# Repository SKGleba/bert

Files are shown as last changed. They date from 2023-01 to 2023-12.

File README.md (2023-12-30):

# bert
*"Bert"* is a nickname given to a UART RPC interface client of PSP2's System Controller.
<br><br>
The PlayStation Vita/TV's System Controller - codenamed *"Ernie"* - is a low-power MCU that handles peripherals such as PMIC, USB controller, physical buttons, touch panels and more. 
It hosts a RPC server accessible from multiple interfaces, each of which has its own set of available commands.<br>
One of the interfaces is UART, enabled by a special *"jig"* circuit that sets specific voltage levels on syscon's voltage sense pins/probes. 
This interface exposes around 100 RPC commands ranging from simple peripheral details retrieving to more complex procedures such as flash programming or alternative SoC boot modes.<br>
In this repository you will find documentation, schematics, diagrams and scripts for interacting with Syscon over the UART interface.
<br><br>

## Hardware
Supported units:
 - DEM-3000 : **only IRT-002**
   - unknown interface-enable procedure on IRT-001 / *"slideys"*
 - CEM-3000 : **supported**
 - PDEL-1000 : **supported**
 - PCH-1000 : **supported**
 - VTE-1000 : **supported**
 - PCH-2000 : **supported**

For all supported units, the UART interface logic level is 1.8v.

### PCH-1000, DEM-3000, CEM-3000, PDEL-1000
On those units, the circuit probes as well as Syscon UART are exposed via the [MultiConnector](https://wiki.henkaku.xyz/vita/UDC#PCH-1XXX_Pinout).
 - Pin 6: Syscon RX
 - Pin 7: Syscon TX
 - Pin 11: Jig Sense 1
 - Pin 12: Jig Sense 2
 - Pin 14: GND

The UART interface is enabled if the *"Jig Sense 1"* probe is at 0.47v-0.738v during *"Jig Sense 2"* probe state change.<br>
State change can be achieved by connecting the probe to GND using a button or jumper wire.<br>
A [MultiConnector breakout board](https://github.com/SKGleba/bert/blob/main/PCBs/multicn-UDC-breakout-kicad.zip) is recommended. 
The biggest challenge is finding a populated connector, we found that the **PCH-ZCL1** *"Sony PlayStation Vita Cradle"* has one, but it is hard to source.<br>
Another possibility is using the motherboard's tiny testpads, or lifting and moving pins on a retail USB MultiConnector cable.<br>

### VTE-1000
On this unit, the circuit probes as well as Syscon and SoC UART are exposed via the [Service Connector](https://www.psdevwiki.com/vita/Service_Connectors).
 - Pin 1: GND
 - Pin 4: Jig Sense 1
 - Pin 6: Jig Sense 2
 - Pin 13: SoC TX (useful)
 - Pin 14: SoC RX (useful)
 - Pin 19: Syscon TX
 - Pin 20: Syscon RX

It is recommended to use the big testpads above the flat connector:

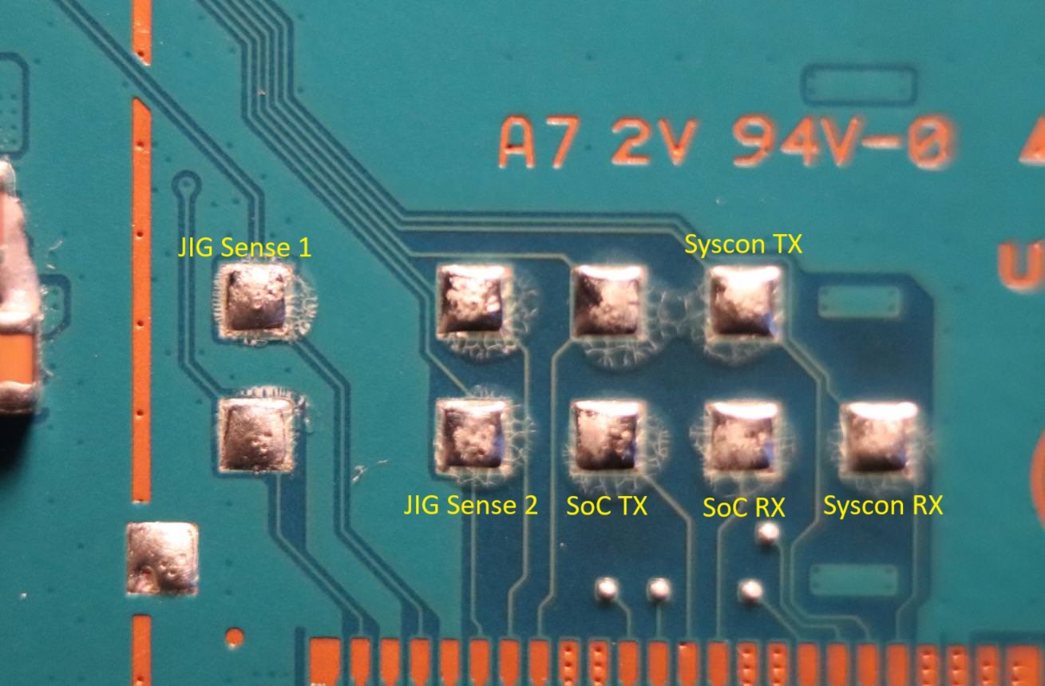
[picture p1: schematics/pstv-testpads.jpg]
pstv-testpads


The UART interface is enabled if the *"Jig Sense 1"* probe is at 0.47v-0.738v during *"Jig Sense 2"* probe state change.<br>
State change can be achieved by connecting the probe to GND using a button or jumper wire.

### PCH-2000
On this unit, the circuit probe as well as Syscon UART are exposed via [microUSB](https://wiki.henkaku.xyz/vita/UDC#PCH-2XXX_Pinout).
 - Pin 2: D- : Syscon TX
 - Pin 3: D+ : Syscon RX
 - Pin 4: ID : Jig Sense
 - Pin 5: GND

The UART interface is enabled if the *"Jig Sense"* probe is at 1.017v-1.14v for at least 32000 Syscon clock cycles. When enabled, a *"UUU"* hello packet is sent over UART.<br>
A microUSB breakout board is recommended, it is also possible to use the motherboard's big testpads.

### AIO
The following circuit will enable the Syscon UART interface on all supported units:

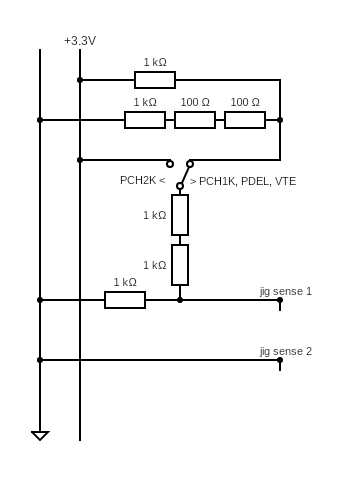
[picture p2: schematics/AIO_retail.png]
AIO-circuit

<br><br>

## Software
The UART RPC interface protocol is a simple message -> reply packet interaction, structured as below:
```C
struct _ernie_cmd {
    uint16_t id; // Command ID
    uint8_t ret; // 0x00 for message, return status for reply
    uint16_t data_size;
    uint8_t data[data_size];
    uint16_t checksum; // ~(all bytes added)
} _ernie_cmd;
```
Each packet is converted to/from ASCII and ends in CRLF, max packet size is 0x40 bytes (ascii 0x80).

### Message
A list of all available commands can be found [in commands.md](commands.md).

### Reply
The reply contains a command return status, currently the following status IDs are known:
 - 0x0 : "OK"
 - 0x1 : "UNK_CMD"
 - 0x2 : "BAD_LEN"
 - 0x3 : "BAD_CHKSUM"
 - 0x4 : "NO_CRLF"
 - 0x5 : "BAD_CMD_FORMAT"
 - 0x10 : "LOCKED_HANDSHAKE"
 - 0x20 : "LOCKED_T1"
 - 0x32 : "BAD_ARG_SIZE"
 - 0x33 : "BAD_ARG"
 - 0x40 : "WRONG_STATE"
 - 0x50 : "WRONG_POWER_STATE"

### Locks
Some commands are locked behind *"locks"* - bits that can be set using other commands.<br>
For example the power control command - 0x105 - requires the T1 *"lock"* to be removed/unlocked by first calling cmd 0x103.<br>
Some commands, such as NVS-read (0x131), might be locked behind multiple *"locks"* - here besides T1, the T8 lock needs to be removed/unlocked first by performing a 3-step keyset 0x1 handshake with cmd 0x110.<br>
Full list of commands with their locks can be found [there](https://github.com/SKGleba/bert/blob/main/commands.md#command-offset-lock) <br>
Un/lock, where Tx is the *"lock"* bitmask:
 - T1: 0x103 / 0x104
 - T2: 0x110 keyset 0x1
 - T4: 0x900 with key / 0x901
 - T8: 0x110 keyset 0xE

### The Script
Provided is a python script that can be used to communicate with the RPC server over UART.<br>
 - requires pyserial, pycryptodome, python 3.10+
```
bert.py raw [COMMAND]                               : send a raw command, only adds checksum           : -----
bert.py nop                                         : ping ernie                                       : 0x100
bert.py mode [USE_FAST?] [USE_BIN?]                 : [true/false] 115200 and binary uart modes        : 0x102
bert.py info                                        : get hardware & ernie info                        : 0x101
bert.py get-date-string                             : get ernie firmware date string                   : 0x107
bert.py power-off / power-on / power-fsm            : set new power state                              : 0x105
bert.py get-power                                   : get current power state                          : 0x106
bert.py get-kr600                                   : read some ID with overlord command 4, off 0x120  : 0x120
bert.py maika-0 [OFFu16]                            : read some data with overlord command 0           : 0x121
bert.py nvs-read [OFFu16] [SIZEu8]                  : read nvs                                         : 0x131
bert.py nvs-read-range [OFFu16] [ENDu16] [STEPu8]   : read and print nvs in STEP-sized blocks          : -----
bert.py nvs-write [OFFu16] [SIZEu8] [DATA]          : write nvs                                        : 0x132
bert.py confzz-ro / confzz-rw                       : block/allow confzz writes                        : 0x144 / 0x143
bert.py confzz-read [OFFu16] [SIZEu8]               : read confzz                                      : 0x141
bert.py confzz-read-range [OFFu16] [ENDu16] [STEPu8]: read and print confzz in STEP-sized blocks       : -----
bert.py confzz-write [OFFu16] [SIZEu8] [DATA]       : write backup confzz                              : 0x142
bert.py confzz-apply                                : write backup confzz to main confzz               : 0x145
bert.py invs-read [OFFu16] [SIZEu8]                 : read internal nvs                                : 0x154
bert.py invs-read-id [IDu8]                         : read internal nvs by id                          : 0x153
bert.py invs-read-range [OFFu16] [ENDu16] [STEPu8]  : read and print internal nvs in STEP-sized blocks : -----
bert.py wipe-nvs                                    : wipe NVS with 0xFF                               : 0x160
bert.py reset / reset-hard                          : soft-reset / hard reset ernie                    : 0x161 / 0x162
bert.py kill                                        : full, hard shutdown of all components            : 0x163
bert.py reset-bic                                   : reset the battery controller                     : 0x182
bert.py unlock-1 / lock-1                           : un/lock the T1 lock                              : 0x103 / 0x104
bert.py unlock-4 / lock-4                           : un/lock the T4 lock with a passcode              : 0x900 / 0x901
bert.py handshake-0 / handshake-1 / handshake-E     : authenticate with the selected keyset            : 0x110
bert.py unlock-qa                                   : unlock the T1 and T8 locks                       : 0x103 + 0x110 (E)
bert.py unlock-nvs                                  : unlock the T1 and T2 locks                       : 0x103 + 0x110 (1)
bert.py unlock-sdboot                               : unlock the T1 lock and boot into SD mode         : 0x103 + 0x110 (0)
bert.py unlock-all                                  : unlock 1,4,qa,nvs,sdboot                         : -----
bert.py [COMMANDu16] <SIZEu16> <DATA>               : execute a command, e.g. '0x105 0x2 03'           : -----
```
<br>

## Notes
 - Some breakout/jig PCB schematics and gerber files can be found in [PCBs](PCBs)
 - Alternative JIG schematics can be found in [schematics](schematics)
 - This project is WIP, the syscon firmware is still being reversed and commands documented.
    - It is not recommended trying unknown commands, they might cause an unrecoverable brick
<br><br>

## Credits
This project was made in collaboration with Proxima.<br><br>
Additional thanks to:
 - yifanlu, for initial syscon JIG research and documentation
 - pop13_13, for help with finding the PCH-2000 JIG circuit
 - S1ngyy, for help with finding the PCH-1000 JIG circuit
 - xyz, for help with finding the VTE-1000 JIG circuit
 - Mathieulh, for alternative PCB schematics and circuits
 - d3s, for the multiCn breakout board
 - SonicMastr, for ideas and early tests
 - Everyone that contributed ideas, tested and helped debug the JIG circuits
 - [henkaku wiki](https://wiki.henkaku.xyz) contributors.

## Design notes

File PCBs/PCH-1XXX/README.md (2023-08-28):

# PCH-1000-JIG-PCB
PCB for JIG on PCH-1000/PDEL-1000 PSVITA

Throughhole design: 



Smaller 0805 footprint PCB: 



Tiny 0805 footprint (design deprecated and no longer supported, using 'Nano' is recommended)
Tiny 0805 footprint 
16.6 x 11mm(0.65 x 0.43 inches)


Nano 0805 footprint (meant to fit within the PCH-ZCL1 craddle) / 5 Volts version available to use with 5V UART modules.
14.8 x 11mm(0.58 x 0.43 inches)




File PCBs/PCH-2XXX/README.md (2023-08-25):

# PCH-2xxx-JIG-PCB
PCB for JIG on PCH-2xxx PSVITA

Nano 0805 footprint 

3.3V Version (on the 3.3V Version VCC on the vita side is left floating so you cannot charge the Vita while JIG is in use)
3.3V Version does not seem to work with FTDI UART when using the FTDI 3.3V module as a voltage input because it appears to output 3.172v rather than a true 3.3v


5V Version (a VCC line has been added for charging, I do not know if it works, it has not been tested; connecting VCC is optional)
Tested on FTDI UART module, resistor values still work when using the UART 5V as a power source despite only outputing 4.930v



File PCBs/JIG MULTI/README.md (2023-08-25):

# JIG MULTI
PCB for JIG for PCH-100x, VTE-100x and PCH-200x PSVITA

* Currently supprorts PCH-1XXX/PDEL-100x, VTE-100x and PCH-2xxx PSVITA at both 3.3V and 5V
Throughhole design only.

* * CAUTION (5V circuit only) Be aware that some UART modules advertised as 5V or with a jumper to 5V do NOT shift the power levels for UART TX/RX which will operate at 3.3V, Please measure voltage using a multimeter on your UART module between TX and GND, if it runs at 3.3V Replace R1 to a 1K ohms resistor in the 5V design.



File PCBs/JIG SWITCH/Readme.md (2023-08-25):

# JIG MULTI SWITCH
PCB for JIG for PCH-100x, VTE-100x and PCH-200x PSVITA

This is an alternative design to the MULTI board which should be closer to what the Sony official JIG may have been like.
Unlike the MULTI board design, this design requires a switch to change between PCH-100X and PCH-200X JIG detect circuits.

* Currently supprorts PCH-1XXX/PDEL-100x, VTE-100x and PCH-2xxx PSVITA at both 3.3V and 5V
* 5V design requires the use of 0 ohms resistors or solder bridges (recommended)
Throughhole design only.

* * CAUTION (5V circuit only) Be aware that some UART modules advertised as 5V or with a jumper to 5V do NOT shift the power levels for UART TX/RX which will operate at 3.3V, Please measure voltage using a multimeter on your UART module between TX and GND, if it runs at 3.3V Replace R1 to a 1K ohms resistor in the 5V design.



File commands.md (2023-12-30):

## Command list tested with a live unit
### 0x0100 - nop
 - response: 0x00
### 0x0101 - get console info
 - response: 0x00
 - output: 3850800011050301030175008040327F
   - last 4 bytes are variable
### 0x0102 - comm settings
 - response: 0x00
 - input: 1byte protocol + 1byte baudrate + 2bytes unknown
   - protocol : 00 ascii, 01 ascii in/binary out
   - baudrate : 00 38400, 01 115200
### 0x0103 - unlock T1
 - response: 0x00
### 0x0104 - lock T1
 - response: 0x00
### 0x0105 - kermit power control
 - response: 0x00 if completed, 0x50 if bad current power state
 - input: requested new power state, 1byte
   - 00 : resp 0x00
     - power-off
   - 02 : resp 0x00
     - power-on
   - 03 : resp 0x00
     - powers on the SoC in SD boot mode, but does not reply to the challenge
     - this is used to talk with internal SoC subsystems via a SPI<->I2C interface
### 0x0106 - get power state
 - response: 0x00
 - output: current power state
   - 0400 : off
   - 0800 : suspended
   - 2000 : on
   - 0002 : unk
   - 0004 : unk
### 0x0107 - get date string
 - response: 0x00
 - output: 32303133313231333135353207000000000000000000000000000000
 - output hex2ascii : 201312131552
### 0x0108
 - response: 0x00
 - output: 
   - slim: 100001C20000000020008043000000003000A90016045300310020050208A90040FFFFFF00000000
   - pstv: 100001920000000020FFFFFF0000000030FFFFFFFFFFFFFF31FFFFFFFFFFFFFF40001ACA00000000
 - input: unknown, min size 2 bytes, only 0000 seems good
### 0x0109 - get task states
 - response: 0x00
 - input: mem buf idx ( 00 / 01 )
   - 00 : output:
     - slim: 0900040000000000320000000000000000000000000000000000000000000000
     - pstv: 0900080000000000510000000000000000000000000000000000000000000000
   - 01 : output:
     - slim: 0802020000000200610009020400000004003200000000000000000000000000
     - pstv: 0802200000002000090009020800000008005100000000000000000000000000
   - the buffers are updated by various tasks, from various states
### 0x0110 - unlock via handshake
 - response: 0x00
 - input: 3-step handshake, ascii size 80 bytes
   - keyset 0x0: start/enter SD boot mode
   - keyset 0x1: unlock T2
   - keyset 0xE: unlock T8
### 0x0120 - get keyring 0x600
 - response: 0x00
 - output: seems to be some serial read from fuses, same as f00d keyring 0x600
   - uses the SPI<->i2c interface in a special boot mode (command 0x105 mode 03)
   - keyring: C477BC5336570D60009F5118052CD5624441E0DD4A3A2E610186E87801010000
   - command: 53BC77C4600D573618519F0062D52C05DDE04144612E3A4A78E8860100000101
### 0x0121 - SoC i2c device 0x40 read by offset
 - response: 0x00
 - input: 16bit offset (BE) for SoC i2c device 0x40
 - output: 32bit value read from offset
   - uses the SPI<->i2c interface in a special boot mode (command 0x105 mode 03)
   - example in=0004 -> out=94000115 (kermit rev)
   - example in=1060 -> out=00000029
   - blacklisted offsets 0x8-0x1000 in release syscon firmware
### 0x0131 - NVS read
 - auth level: T2
 - response: 0x00
 - input: 2byte offset + 1byte size
 - output: data read from given offset
### 0x0132 NVS write
 - auth level: T2
 - response: 0x00
 - input: 2byte offset + 1byte size + sizeBytes data, min size 6 ascii bytes
 - output: data read from given offset
### 0x0140 - ConfZZ param?
 - response: 0x00
 - output: 32bit values from the 0x10 field before both main and backup ConfZZ
   - slim: 5800050058000400
   - pstv: 5000040050000300
     - whole buf 03B800: 43 6F 6E 66 5A 5A F0 03 50 00 03 00 E4 51 FF FF
     - whole buf 03BC00: 43 6F 6E 66 5A 5A F0 03 50 00 04 00 7E 52 FF FF
### 0x0141 - ConfZZ read
 - response: 0x00
 - input: 2byte offset + 1byte size, max offset 0x3EF, max size 0x20
 - output: ConfZZ data of size read from offset
### 0x0142 - ConfZZ write-backup
 - response: 0x00
 - input: 2byte offset + 1byte size + sizeBytes data, max offset 0x3EF, max size 0x20
 - data is written to backup ConfZZ
### 0x0143 - Unlock 0x142
 - response: 0x00
### 0x0144 - Lock 0x142
 - response: 0x00
### 0x0145 - Switch active ConfZZ?
 - response: 0x00
 - active ConfZZ is changed / backup ConfZZ is written to main?
### 0x0146
 - computes and checks some sha1, integrity checks?
 - response: 0x00 if all ok
 - input: unk, seems like 3 bytes followed by a sha1?
### 0x0147
 - computes and checks some sha1, integrity checks?
 - response: 0x00 if all ok
 - input: unk, seems like 3 bytes followed by a sha1?
### 0x0150
 - response: 0x00
 - output: some invs flags preset?
   - slim: 0900001100000000
   - pstv: 100001AA00000000
### 0x0151 - Unlock INVS writes (0xAA)
 - response: 0x00
 - unlocks 0x155 & 0x156, writes 0xAA to invs+1
### 0x0152 - Lock INVS writes
 - response: 0x00
 - locks 0x155 & 0x156, writes 0x00 to invs+1
### 0x0153 - internal NVS read by id
 - response: 0x00
 - input: unknown, min ascii size 4 bytes, read data id?, max id 0x1D
   - 00 : output:
     - slim: 01AA0900
     - pstv: 01001000
   - 01 : output 6A000000
   - 02 : output 06000000
   - 03,06,07,0C-10,12,14,16,1A,1D : output 00
   - 04,19 : output 02
   - 05 : output 1400
   - 08,18 : output 01
   - 09,0A,0B,17 : output 0000
   - 11 : output 07
   - 13 : output 08
   - 15 : output 03
   - 1B : output 2800
   - 1C : output 29
### 0x0154 - internal NVS read
 - response: 0x00
 - input: 2byte offset + 1byte size, max offset 0x3F, max size 0x20
 - output: unknown data of size read from offset, seems to contain data from 0x153
### 0x0155
 - response: 0x00
 - input: unknown, min ascii size 4 bytes, ?write data?
### 0x0156
 - response: 0x00 (?apply data?)
### 0x0157 - Unlock INVS writes (0x11)
 - response: 0x00
 - unlocks 0x155 & 0x156, writes 0x11 to invs+1
### 0x0160 - DEPERSONALIZE
 - response: 0x00
 - input: unknown, min size 2 ascii bytes
   - 01: loong pause, no uuu
   - 02: FORMATS S/NVS
### 0x0161 - ?hard? reset syscon
 - response: 0x00
 - causes ?soft reset?, UUU sent again, console shutdown
### 0x0162 - ?soft? reset syscon
 - response: 0x00
 - causes ?soft reset?, UUU is sent again, faster than 0x162
### 0x0163
 - response: 0x00
 - input: unknown, min size 2 ascii bytes
   - 5A: seems to shut down kermit and reset locks, does not UUU 
### 0x0168
 - response: 0x00
 - output: 
   - slim: 70033737
   - pstv: 70033535
### 0x0170
 - response: 0x00
 - output: 
   - slim: 01420000250000001B0CFFFFF8000F00000000000018
   - pstv: 0102000100
### 0x0171
 - response: 0x00
 - output: 8040327FFFFF61EDF4
   - output is variable
### 0x0172
 - response: 0x00
 - output: CC640500FFFFFFFF00
   - output is variable
### 0x0180
 - response: 0x00
 - output: 
   - slim: 8607B70FF200F70056000000
   - pstv: D007A00F2C012C0100000000
### 0x0181
 - response: 0x00
 - output: 
   - slim: 110080016201000000000000
   - pstv: 000000000000000000000000
### 0x0182 - reset the battery controller
 - response: 0x00
 - causes ?hard reset?, UUU is sent again after a longer period (~6 seconds)
   - nothing on PSTV - makes me think its the battery controller
### 0x0183
 - response: 0x00
 - unlocks 0x184,0x185,0x186,0x187,0x188,0x189
### 0x0184
 - response: 0x00
### 0x0185
 - response: 0x33
### 0x0186
 - response: 0x00
### 0x0187
 - response: 0x33
### 0x0188
 - response: 0x00
### 0x0189
 - response: 0x00
### 0x018A
 - response: 0x00
 - output: 
   - slim: 40000000
   - pstv: 00000000
### 0x018B
 - response: 0x00
 - output: 01
### 0x018C
 - response: 0x00
 - output: 
   - slim: 0C
   - pstv: 09
### 0x018D
 - response: 0x00
 - output: 
   - slim: 00
   - pstv: 08
### 0x018E
 - response: 0x00
 - output: 
   - slim: 01
   - pstv: 0C
### 0x0190
 - response: 0x00
 - output: 0100000000010000
### 0x01A0
 - response: 0x00
 - output: 0000000000000000000000000000000000000000
### 0x01A1
 - response: 0x00
 - output: 808080808080808080808080
### 0x01B0
 - response: 0x00
 - output: 0000000000000000
### 0x01C0
 - response: 0x00
 - output: 01550000
### 0x01C1
 - response: 0x00
### 0x01C2
 - response: 0x00
### 0x01C3
 - response: 0x00
 - unlocks 0x1C1,0x1C4
### 0x01C4
 - response: 0x00
 - output: 36300301FF000400
 - input: unknown, min ascii size 4 bytes, ?id?, max id 0x29
 - output: unknown, data read from id? for example id=01->data=A408020120000C0C
### 0x01D0
 - response: 0x98
### 0x01D1
 - response: 0x98
### 0x01D2
 - response: 0x00
 - output: 0000000000010000
### 0x0300 write to shared jig-kermit buffer
 - response: 0x00
 - input: message to kermit, max ascii size 80 bytes
 - sets some key
### 0x0301 read from jig-kermit shared buffer
 - response: 0x00
 - output: message from kermit, ascii size 80 bytes
### 0x0900 - unlock T4
 - response: 0x00
 - input: password, ascii size 32 bytes
### 0x0901 - lock T4
 - response: 0x00
### 0x0910
 - response: 0x33
### 0x0911
 - response: 0x33
### 0x0912
 - response: 0x33
### 0x0913
 - response: 0x33
### 0x0914
 - response: 0x33
### 0x0915
 - response: 0x33
### 0x0916
 - response: 0x00
 - output: 1B010600035402010100010000000000
### 0x0917
 - response: 0x00
 - output: 2D3A0543
### 0x0930
 - response: 0x00
 - output: 
   - slim: 01C2
   - pstv: 0192
### 0x0931
 - response: 0x00
 - output: 
   - slim: 8043
   - pstv: FFFF
### 0x0932
 - response: 0x00
 - output: 
   - slim: 2005A900160453000208A900
   - pstv: FFFFFFFFFFFFFFFFFFFFFFFF
### 0x0940
 - response: 0x00
 - output: 0300
 - input: unknown
   - : output 05A9 resp 0x60
   - 00-03,08-0D,24,25,33-35,37,41,44,48 : output 0300
   - 04-07,0F-1F,36,38-3F : output 0400
   - 0E : output 0600
   - 20-22,40,43,46,47,49-4F : output 0200
   - 23,26-32,90-9F : output 0100
   - 42,71,72 : output 0004
   - 45 : output 0404
   - 50 : output 5541
   - 51,54 : output 4105
   - 52,55 : output 1000
   - 53 : output AA81
   - 56-5F,80,A0-A3,A5-A7,AA-B2,F0-FF : output 0000
   - 60-70 : output FFF0
   - 73 : output 0005
   - 74-7F : output 0101
   - 81 : output 1500
   - 82-85 : output 1700
   - 86-8F : output 0F00
   - B3-BF : output F000
   - A9,C0-CF : output 8000
   - D0-EF : output 01C2
### 0x0941
 - response: 0x00
 - input: unknown, min ascii size 2 bytes
 - writes somewhere or sets some flag for 0x942
### 0x0942
 - response: 0x00
 - input: unknown, min ascii size 2 bytes
 - output: 0000 unless written with 0x941, mashed with input
### 0x0943
 - response: 0x00
 - input: unknown, min ascii size 2 bytes
### 0x0944
 - response: 0x00
 - output: 9801
### 0x0945
 - response: 0x00
 - input: unknown, min ascii size 2 bytes
### 0x0952
 - response: 0x00
 - causes ?soft reset?, UUU is sent again after around 3s
### 0x0953
 - response: 0x00
 - output: 1C000000A60BA30B
### 0x0961
 - response: 0x00
 - output: 8080808080808080
### 0x0962
 - response: 0x00
 - output: 0080008000800080
### 0x0963
 - response: 0x00
 - output: 00000000000000000000000000000000
### 0x0964
 - response: 0x00
 - output: 0080008000800000008000800080000000800080008000000080008000800000
### 0x0965
 - response: 0x00
 - output: 0000C0FF0000C0FF0000C0FF0000C0FF

## Command, offset, lock
<ID, OFFSET, AUTH> <br>
<100h, sub_1E814, 0>                   
<101h, sub_1E830, 0>                   
<102h, sub_1E8B5, 0>                   
<103h, sub_1EA0C, 0>                   
<104h, sub_1EA3D, 0>                   
<105h, sub_1EA6E, 1>                   
<106h, sub_1EC2F, 0>                   
<107h, sub_1EC84, 0>                   
<108h, sub_1F43C, 0>                   
<109h, sub_1F4B2, 0>                   
<110h, do_handshake_0_1_E, 1>          
<120h, sub_1ED5F, 1>                   
<121h, sub_1EE1C, 1>                   
<131h, sub_1EFE9, 3>                   
<132h, sub_1F091, 3>                   
<140h, sub_1F2CE, 0>                   
<141h, sub_1F317, 9>                   
<142h, sub_1F541, 9>                   
<143h, sub_1F5E3, 9>                   
<144h, sub_1F624, 9>                   
<145h, sub_1F665, 9>                   
<146h, sub_1F6A6, 9>                   
<147h, sub_1F753, 9>                   
<148h, sub_1F801, 9>                   
<150h, sub_1FA55, 1>                   
<151h, sub_1FAB6, 1>                   
<152h, sub_1FAF0, 9>                   
<153h, sub_1FB29, 9>                   
<154h, sub_1FBC1, 9>                   
<155h, sub_1FC7E, 9>                   
<156h, sub_1FCD0, 9>                   
<157h, sub_1FD04, 1>                   
<160h, sub_1FD3E, 9>                   
<161h, sub_1FECC, 9>                   
<162h, sub_1FF00, 9>                   
<163h, sub_1FF2D, 9>                   
<168h, sub_1F3C2, 1>                   
<170h, sub_1F127, 9>                   
<171h, sub_1F916, 9>                   
<172h, sub_1F9BD, 9>                   
<180h, sub_1FF8E, 1>                   
<181h, sub_1FFC5, 9>                   
<182h, sub_1FFFC, 9>                   
<183h, sub_200A6, 9>                   
<184h, sub_200EE, 9>                   
<185h, sub_20136, 9>                   
<186h, sub_2017E, 9>                   
<187h, sub_201C6, 9>                   
<188h, sub_2020E, 9>                   
<189h, sub_20256, 9>                   
<18Ah, sub_2029E, 9>                   
<18Bh, sub_202CC, 9>                   
<18Ch, sub_202FA, 9>                   
<18Dh, sub_20328, 9>                   
<18Eh, sub_20356, 9>                   
<18Fh, sub_20384, 9>                   
<190h, sub_20033, 9>                   
<191h, sub_203F6, 9>                   
<192h, sub_20447, 9>                   
<1A0h, sub_2064C, 1>                   
<1A1h, sub_206D9, 1>                   
<1B0h, sub_20743, 1>                   
<1B2h, sub_20788, 9>                   
<1C0h, sub_207FA, 1>                   
<1C1h, sub_20884, 1>                   
<1C2h, sub_208B6, 1>                   
<1C3h, sub_208E8, 1>                   
<1C4h, sub_2091A, 1>                   
<1D0h, sub_209BA, 9>                   
<1D1h, sub_209D8, 9>                   
<1D2h, sub_1F3FF, 1>                   
<1D3h, sub_210E0, 9>                   
<1D4h, sub_210FE, 1>                   
<1D5h, sub_2111C, 9>                   
<1E0h, sub_2113A, 1>                   
<1E1h, sub_21171, 1>                   
<1E2h, sub_211C2, 1>                   
<1E3h, sub_211F9, 1>                   
<300h, sub_1F1AA, 0>                   
<301h, sub_1F1FF, 0>                   
<900h, sub_20A05, 0>  Send Passphrase? passphrase is: 93CE8EBEDF7F69A96F35DDE3BECB97D5                 
<901h, sub_20A69, 0>                   
<910h, sub_20A96, 4>                   
<911h, sub_20B22, 4>                   
<912h, sub_20B5B, 4>                   
<913h, sub_20BE7, 4>                   
<914h, sub_20C6C, 4>                   
<915h, sub_20CF8, 4>                   
<916h, sub_20D7E, 4>                   
<917h, sub_20DCE, 0Ch>                 
<930h, sub_20E33, 4>                   
<931h, sub_20E33, 4>                   
<932h, sub_20E33, 4>                   
<940h, sub_20E92, 0Ch>                 
<941h, sub_20F0C, 0Ch>                 
<942h, sub_20E92, 0Ch>                 
<943h, sub_20F0C, 0Ch>                 
<944h, sub_20E92, 0Ch>                 
<945h, sub_20F0C, 0Ch>                 
<952h, sub_20FBE, 0Ch>                 
<953h, sub_21019, 4>                   
<954h, sub_21050, 4>                   
<955h, sub_21098, 4>                   
<961h, sub_21220, 4>                   
<962h, sub_21275, 4>                   
<963h, sub_212C0, 4>                   
<964h, sub_2130C, 4>                   
<965h, sub_2147A, 4>                   
<967h, sub_214C6, 0Ch>                 
<968h, sub_21501, 0Ch>                 
<969h, sub_2153D, 0Ch>

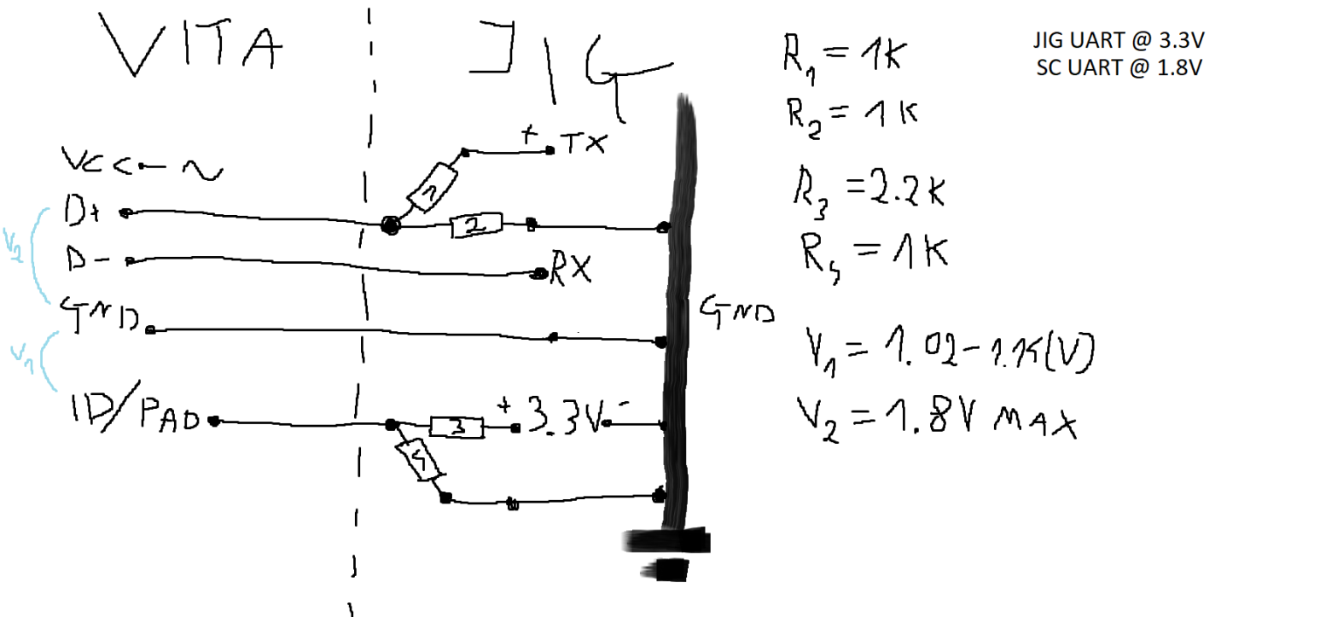
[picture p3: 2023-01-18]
schematics/PCH2k.png

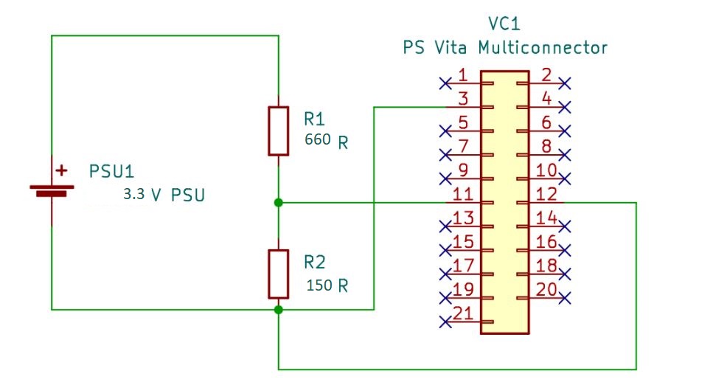
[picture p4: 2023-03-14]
schematics/PCH1k.JPG

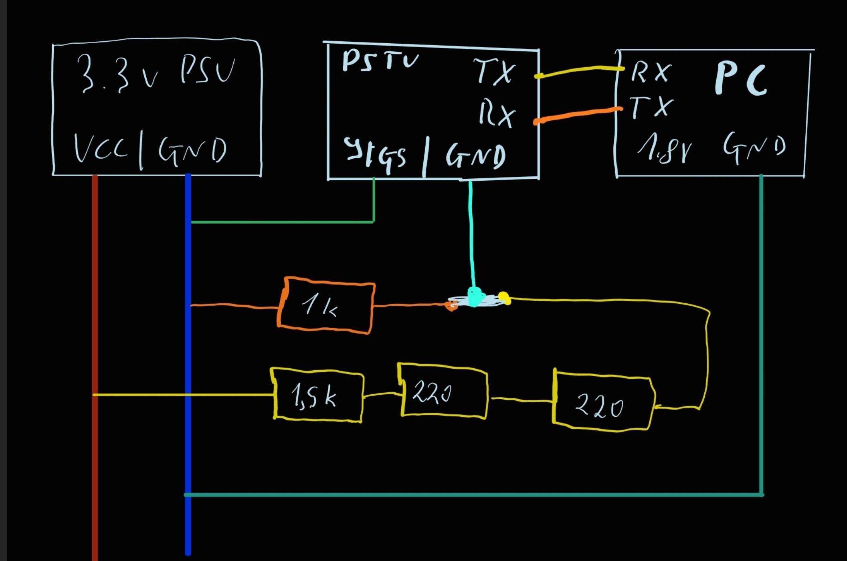
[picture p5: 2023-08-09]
schematics/VTE-alt.jpg

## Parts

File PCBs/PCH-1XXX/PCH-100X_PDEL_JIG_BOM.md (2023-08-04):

if you want to build JIG you will need the following: 

Other board designs follow the same BOM but resistor footprint is changed to 0805

- PSV Craddle PCH-ZCL1

Can be found on eBay or Yahoo Auctions Japan

- FTDI RS232 USB module (set to 3.3v, you may set to 5V ONLY if you use the 5V version of the board)

https://www.amazon.com/FainWan-Converter-Breakout-Compatible-Ar-duino/dp/B09JZC6TC8/

https://www.amazon.com/HiLetgo-FT232RL-Converter-Adapter-Breakout/dp/B00IJXZQ7C

- 3 x 1k Ohms resistors

https://www.amazon.com/BOJACK-Values-Resistor-Resistors-Assortment/dp/B08FHPJ5G8

- 1 x 220 Ohms resistor

https://www.amazon.com/BOJACK-Values-Resistor-Resistors-Assortment/dp/B08FHPJ5G8

- Enamel/Magnet wire (0.1mm to solder pins 6 and 7 on the craddle UDC connector)

https://www.amazon.com/Enameled-Winding-Thickness-Connecting-Soldering/dp/B0987VKL55

- Insulated wires (regular multi core AWG30 or the like works fine) to solder to the Craddle FFC for Pins 3; 11; 12

https://www.amazon.com/StrivedayTM-Flexible-Silicone-electronic-electrics/dp/B01KQ2JNLI

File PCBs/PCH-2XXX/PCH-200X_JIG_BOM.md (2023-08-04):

if you want to build JIG you will need the following: 

- USB Micro B (male) to usb A cable (male) or USB Breakout board

- FTDI RS232 USB module (set to 3.3v, you may set to 5V ONLY if you use the 5V version of the board)

https://www.amazon.com/FainWan-Converter-Breakout-Compatible-Ar-duino/dp/B09JZC6TC8/

https://www.amazon.com/HiLetgo-FT232RL-Converter-Adapter-Breakout/dp/B00IJXZQ7C

- 3 x 1k Ohms resistors using 0805 footprint

- 1 x 2.2k Ohms resistorusing 0805 footprint

- Insulated (dupont) to connect to the RS232 module

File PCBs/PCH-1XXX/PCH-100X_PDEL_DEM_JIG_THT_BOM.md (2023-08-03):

if you want to build JIG using the Throughhole board you will need the following: 

Other board designs follow the same BOM but resistor footprint is changed to 0805

- PSV Craddle PCH-ZCL1

Can be found on eBay or Yahoo Auctions Japan

- Breakout board (until the PCB I designed is tested)

https://www.amazon.com/ELEGOO-Prototype-Soldering-Compatible-Arduino/dp/B072Z7Y19F/

https://www.amazon.com/HiLetgo-Finished-Prototype-Circuit-Breadboard/dp/B00FXHXT80/

- FTDI RS232 USB module (set to 3.3v, you may set to 5V ONLY if you use the 5V version of the board)

https://www.amazon.com/FainWan-Converter-Breakout-Compatible-Ar-duino/dp/B09JZC6TC8/

https://www.amazon.com/HiLetgo-FT232RL-Converter-Adapter-Breakout/dp/B00IJXZQ7C

- 3 x 1k Ohms resistors (on normal design) OR 2 x 1k Ohms resistors (on ALT design)

https://www.amazon.com/BOJACK-Values-Resistor-Resistors-Assortment/dp/B08FHPJ5G8

- 2 x 330 Ohms resistors (only for ALT design)

https://www.amazon.com/BOJACK-Values-Resistor-Resistors-Assortment/dp/B08FHPJ5G8

- 1 x 150 Ohms resistor (only for ALT design)

https://www.amazon.com/BOJACK-Values-Resistor-Resistors-Assortment/dp/B08FHPJ5G8

- 1 x 220 Ohms resistor (only for normal design)

https://www.amazon.com/BOJACK-Values-Resistor-Resistors-Assortment/dp/B08FHPJ5G8

- Enamel/Magnet wire (0.1mm to solder pins 6 and 7 on the craddle UDC connector)

https://www.amazon.com/Enameled-Winding-Thickness-Connecting-Soldering/dp/B0987VKL55

- Insulated wires (regular multi core AWG30 or the like works fine) to solder to the Craddle FFC for Pins 3; 11; 12

https://www.amazon.com/StrivedayTM-Flexible-Silicone-electronic-electrics/dp/B01KQ2JNLI

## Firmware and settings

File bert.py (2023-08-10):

#!/usr/bin/env python3
'''

PSVita v2 Syscon JIG Client by Proxima & SKGleba (R)

'''
import sys, os, struct, code, binascii
import serial, time, re, math
from Crypto.Cipher import AES
import random

DEFAULT_PORT = 'COM14'

secret1data = {
    0x0: "80996FBBC8B4EBA30595F4D379A23BD0",
    0x1: "8C20B6FABD2236F772AA283B8C82B13E",
    0xB: "CF2E93E9F94E28CCA48026134C7C77CE",
    0xE: "AD2F322F4256C49D1848818F0FDD81BE",
    0xF: "C86B51FB019A207F32118E55462D5008"
}

secret2data = {
    0xF: "B01103B0623832D62540B56333D6E11D"
}

key1table = {
    0x0: "EF685D2E33C7D029A1A2EE646BE39D41",
    0x1: "87DC6ECFF1CA5D709B01AEF69EA6B283",
    0xB: "BB644721CB4C55072E83177BEB3BBEE9",
    0xE: "4ACE3A668AAEBB11793C432FB8A4CE88",
    0xF: "50E4C3A77264167C409C72A9B57A8609"
}

key2table = {
    0x0: "CE7867DE57575C008D998281E8DA5912",
    0x1: "51EB8DD39B0585CE915F3BFF609C9563",
    0xB: "DC6B6EE0F457DF0E7BAD1C5EA338027F",
    0xE: "1CBAE93DE883557C8AA14886786BE227",
    0xF: "9E34087C48985B4B351A63572D9B481B"
}

key3table = {
    0xF: "EBE3460D84A41754AC441368CF0200D8"
}

CMD900_PWD = "93CE8EBEDF7F69A96F35DDE3BECB97D5"

STATUS_CODES = {
    0x0 : "OK",
    0x1 : "UNK_CMD",
    0x2 : "BAD_LEN",
    0x3 : "BAD_CHKSUM",
    0x4 : "NO_CRLF",
    0x5 : "BAD_CMD_FORMAT",
    0x10 : "LOCKED_HANDSHAKE",
    0x20 : "LOCKED_T1",
    0x32 : "BAD_ARG_SIZE",
    0x33 : "BAD_ARG",
    0x40 : "WRONG_STATE",
}

def read_all(port, size):
    data = b''
    while len(data) < size:
        data += port.read(size - len(data))
    assert len(data) == size
    return data
    
silent_mode = 0
def print_packet(pinfo, cmdp, outbound):
    if silent_mode == 0:
        print(pinfo + ": 0x" + cmdp[2:4] + cmdp[0:2] + " 0x" + cmdp[8:10] + cmdp[6:8] + " [ " + cmdp[10:-4] + " ] 0x" + cmdp[-2:] + cmdp[-4:-2], end="")
    elif silent_mode == 1:
        if not outbound:
            print("-", end="")
        if cmdp[10:-4] != "":
            print(" [ " + cmdp[10:-4] + " ]", end="")
        else:
            print(" [ ]", end="")
    if silent_mode != 2:
        if not outbound:
            cv_status = int(cmdp[4:6], 16)
            if cv_status in STATUS_CODES:
                print(" <" + STATUS_CODES[cv_status] + ">", end="")
            else:
                print(" <0x" + "{:02X}".format(cv_status) + ">", end="")
        print("")
        

class JIGClient(object):
    def __init__(self):
        self.is_open = False
        
    def open(self, uart_port, baud):
        if self.is_open == False:
            self._port = serial.Serial(uart_port, baudrate=baud, timeout=0)
            self.is_open = True
        
    def close(self):
        if self.is_open == True:
            self._port.close()
            self.is_open = False

    def read_all(self, size):
        return read_all(self._port, size)

    def read_line(self, terminator=b'\n'):
        data = []
        c = b''
        while c != terminator:
            c = self.read_all(1)
            data.append(c)
        return b''.join(data)
 
    def checksum(self,s):
        csum=0
        for x in s:
            csum = (csum + x) & 0xFFFF
        return bytearray(int((~csum) & 0xFFFF).to_bytes(2,"little"))

    def get_resp(self):
        x= bytes.fromhex(self.read_line().decode("ascii"))
        return x

    def send_cmd(self, cmd, loglevel):
        bcmd = cmd + self.checksum(cmd)
        uartcmd = bcmd.hex().upper() + "\r\n"
        if loglevel != 0 and silent_mode == 1:
            print("+", end="")
        if loglevel == 2:
            print_packet("SEND", uartcmd[:-2], True)
        elif loglevel == 1 and silent_mode != 2:
            if silent_mode == 1:
                print(uartcmd[0:-2])
            else:
                print("SEND: " + uartcmd[0:-2])
        self._port.reset_input_buffer()
        self._port.reset_output_buffer()
        self._port.write(uartcmd.encode("ascii"))
        
client = JIGClient() # hardcode this, redefine if you need a diff client

def cmd_x110(keyv):
    if silent_mode != 2:
        print("Starting 3Auth")
    #                      0 1 2 3 4 5 6 7 8 9 A B C D E F 101112131415161718191A1B1C1D1E1F202122232425262728292A2B2C2D
    #                      10010050003001000E00000000BABEF00DBEEFBABE000000000000000000000000000000000000000000000000
    c = bytearray.fromhex("100100500030000000000000000000000000000000000000000000000000000000000000000000000000000000")
    c[8] = keyv
    client.send_cmd(c, 2)
    response =client.get_resp()
    print_packet("RESP", response.hex().upper(), False)
    if response[2] != 0:
        if silent_mode != 2:
            print("ERROR: Bad Response (" + response[2].hex() + ")")
        exit(0)
    c[6] = 1
    c[0xD:0x15] = random.randbytes(8)
    # Send step 1 challenge
    client.send_cmd(c, 2)
    response =client.get_resp()
    print_packet("RESP", response.hex().upper(), False)
    if response[2] != 0 or response[7] !=0:
        if silent_mode != 2:
            print("ERROR: Bad Response (" + response[2].hex() + "-" + response[7].hex() + ")")
        exit(0)

    payload = response[0xD:0x2D]
    
    shared_secret = bytes.fromhex(secret1data[c[8]])
    key1 = bytes.fromhex(key1table[c[8]])
    key2 = bytes.fromhex(key2table[c[8]])
    iv = bytes(0x10)
    plain = AES.new(key1, AES.MODE_CBC, iv).decrypt(payload)
    if plain[0x10:0x20] == shared_secret:
        handplain = plain[8:0x10] + plain[0:8] + iv
        handcrypt = AES.new(key2, AES.MODE_CBC, iv).encrypt(handplain)
        c[6] = 3
        c[0xD:0x2D] = handcrypt
        client.send_cmd(c, 2)
        response =client.get_resp()
        print_packet("RESP", response.hex().upper(), False)
        if silent_mode != 2:
            if response[7] == 0 and response[6] == 0xFF:
                print("Successful 3Auth")
            else:
                print("ERROR: Failed 3Auth (" + response[2].hex() + "-" + response[6].hex() + "-"+ response[7].hex() + ")")
    elif silent_mode != 2:
        print("ERROR: Invalid Handshake secret")

def send_simple_cmd(cmd_ascii):
    c = bytearray.fromhex(cmd_ascii)
    client.send_cmd(c, 2)
    response = client.get_resp()
    print_packet("RESP", response.hex().upper(), False)

def handle_cmd(user_cmd, argv):
    if client.is_open == False:
        client.open(DEFAULT_PORT, 38400)
    match user_cmd:
        case "raw":
            client.send_cmd(bytearray.fromhex(argv[2]), 1)           
            response = client.get_resp()
            if silent_mode == 0:
                print("RESP: " + response.hex().upper())
            elif silent_mode == 1:
                print("-" + response.hex().upper())
        case "nop":
            send_simple_cmd("0001000000")
        case "info":
            send_simple_cmd("0101000000")
        case "mode":
            send_simple_cmd("0201000800" + ("01" if argv[2] == "true" else "00") + ("01" if argv[3] == "true" else "00") + "0000")
        case "unlock-1":
            send_simple_cmd("0301000000")
        case "lock-1":
            send_simple_cmd("0401000000")
        case "power-off":
            send_simple_cmd("050100020000")
        case "power-on":
            send_simple_cmd("050100020002")
        case "power-fsm":
            send_simple_cmd("050100020003")
        case "get-power":
            client.send_cmd(bytearray.fromhex("0601000000"), 0)
            response =client.get_resp()
            if silent_mode != 2:
                match response.hex()[10:-4].upper():
                    case "0400":
                        print("STATE_OFF")
                    case "0800":
                        print("STATE_SUSPEND")
                    case "2000":
                        print("STATE_ON")
                    case _:
                        print("UNK STATE : " + response.hex()[10:-4].upper())
        case "handshake-0":
            cmd_x110(0x0)
        case "handshake-1":
            cmd_x110(0x1)
        case "handshake-E":
            cmd_x110(0xE)
        case "get-kr600":
            send_simple_cmd("2001000000")
        case "maika-0":
            cv_off = "{:04X}".format(int(argv[2][2:], 16))
            send_simple_cmd("2101000400" + cv_off)
        case "nvs-read":
            cv_off = "0x{:04X}".format(int(argv[2][2:], 16))
            cv_sz = "0x{:02X}".format(int(argv[3][2:], 16))
            cv_cmd = "3101000600" + cv_off[4:6] + cv_off[2:4] + cv_sz[2:4]
            send_simple_cmd(cv_cmd)
        case "nvs-read-range":
            cv_bsz = int(argv[4][2:], 16)
            for x in range(int(argv[2][2:], 16), int(argv[3][2:], 16), cv_bsz):
                cv_off = "0x" + "{:04X}".format(x)
                cv_cmd = "3101000600" + cv_off[4:6] + cv_off[2:4] + "{:02X}".format(cv_bsz)
                client.send_cmd(bytearray.fromhex(cv_cmd), 0)
                response =client.get_resp()
                if silent_mode != 2:
                    print(response.hex()[10:-4].upper())
        case "nvs-write":
            cv_off = "0x{:04X}".format(int(argv[2][2:], 16))
            cv_sz = "0x{:02X}".format(int(argv[3][2:], 16))
            cv_cmd = "320100" + "{:02X}".format((int(cv_sz[2:4], 16) * 2) + 6) + "00" + cv_off[4:6] + cv_off[2:4] + cv_sz[2:4] + argv[4]
            send_simple_cmd(cv_cmd)
        case "confzz-read":
            cv_off = "0x{:04X}".format(int(argv[2][2:], 16))
            cv_sz = "0x{:02X}".format(int(argv[3][2:], 16))
            cv_cmd = "4101000600" + cv_off[4:6] + cv_off[2:4] + cv_sz[2:4]
            send_simple_cmd(cv_cmd)
        case "confzz-read-range":
            cv_bsz = int(argv[4][2:], 16)
            for x in range(int(argv[2][2:], 16), int(argv[3][2:], 16), cv_bsz):
                cv_off = "0x" + "{:04X}".format(x)
                cv_cmd = "4101000600" + cv_off[4:6] + cv_off[2:4] + "{:02X}".format(cv_bsz)
                client.send_cmd(bytearray.fromhex(cv_cmd), 0)
                response =client.get_resp()
                if silent_mode != 2:
                    print(response.hex()[10:-4].upper())
        case "confzz-write":
            cv_off = "0x{:04X}".format(int(argv[2][2:], 16))
            cv_sz = "0x{:02X}".format(int(argv[3][2:], 16))
            cv_cmd = "420100" + "{:02X}".format((int(cv_sz[2:4], 16) * 2) + 6) + "00" + cv_off[4:6] + cv_off[2:4] + cv_sz[2:4] + argv[4]
            send_simple_cmd(cv_cmd)
        case "confzz-rw":
            send_simple_cmd("4301000000")
        case "confzz-ro":
            send_simple_cmd("4401000000")
        case "confzz-apply":
            send_simple_cmd("4501000000")
        case "invs-read-id":
            cv_id = "0x{:02X}".format(int(argv[2][2:], 16))
            cv_cmd = "5301000400" + cv_id[2:4] + "00"
            send_simple_cmd(cv_cmd)
        case "invs-read":
            cv_off = "0x{:04X}".format(int(argv[2][2:], 16))
            cv_sz = "0x{:02X}".format(int(argv[3][2:], 16))
            cv_cmd = "5401000600" + cv_off[4:6] + cv_off[2:4] + cv_sz[2:4]
            send_simple_cmd(cv_cmd)
        case "invs-read-range":
            cv_bsz = int(argv[4][2:], 16)
            for x in range(int(argv[2][2:], 16), int(argv[3][2:], 16), cv_bsz):
                cv_off = "0x" + "{:04X}".format(x)
                cv_cmd = "5401000600" + cv_off[4:6] + cv_off[2:4] + "{:02X}".format(cv_bsz)
                client.send_cmd(bytearray.fromhex(cv_cmd), 0)
                response =client.get_resp()
                if silent_mode != 2:
                    print(response.hex()[10:-4].upper())
        case "wipe-nvs":
            send_simple_cmd("600100020002")
        case "reset":
            send_simple_cmd("6101000000")
        case "reset-hard":
            send_simple_cmd("6201000000")
        case "kill":
            send_simple_cmd("63010002005A")
        case "reset-bic":
            send_simple_cmd("8201000000")
        case "unlock-4":
            send_simple_cmd("0009002000" + CMD900_PWD)
        case "lock-4":
            send_simple_cmd("0109000000")
        case "unlock-qa":
            handle_cmd("unlock-1", argv)
            handle_cmd("handshake-E", argv)
        case "unlock-nvs":
            handle_cmd("unlock-1", argv)
            handle_cmd("handshake-1", argv)
        case "unlock-sdboot":
            handle_cmd("unlock-1", argv)
            handle_cmd("handshake-0", argv)
        case "unlock-all":
            handle_cmd("unlock-1", argv)
            handle_cmd("handshake-E", argv)
            handle_cmd("handshake-1", argv)
            handle_cmd("handshake-0", argv)
            handle_cmd("unlock-4", argv)
        case "shbuf-read":
            send_simple_cmd("0103000000")
        case "shbuf-write":
            send_simple_cmd("000300" + "{:02X}".format(len(argv[2])) + "00" + argv[2])
        case _:
            if user_cmd[:2] == "0x":
                cv_user_cmd = "0x{:04X}".format(int(user_cmd[2:], 16))
                if len(argv) > 2:
                    cv_user_cmd_size = "0x{:04X}".format(int(argv[2][2:], 16))
                else:
                    cv_user_cmd_size = "0x0000"
                cv_cmd = cv_user_cmd[4:6] + cv_user_cmd[2:4] + "00" + cv_user_cmd_size[4:6] + cv_user_cmd_size[2:4]
                if len(argv) > 3:
                    cv_cmd += argv[3]
                return handle_cmd(cv_cmd, argv)
            else:
                try:
                    send_simple_cmd(user_cmd)
                except KeyboardInterrupt:
                    pass
                except:
                    print("command not found and/or malformed input")

def interactive():
    global silent_mode
    print("\nWelcome to interactive mode")
    print("use !help to display usage info")
    while 1:
        print("")
        uinput = input('> ')
        uinput_argv = uinput.split()
        uinput_argv.insert(0, "interactive")
        cmd = uinput_argv[1]
        match cmd:
            case "!help":
                helper(True, ">")
            case "!exit":
                break
            case "!open":
                try:
                    client.open(uinput_argv[2], int(uinput_argv[3]))
                except Exception as e:
                    print(e)
            case "!close":
                client.close()
            case "!wait":
                if client.is_open == True:
                    try:
                        line = client.get_resp()
                        if silent_mode != 2:
                            print_packet("ERNIE", line.hex().upper())
                    except Exception as e:
                        print(e)
                    except KeyboardInterrupt:
                        pass
                else:
                    print("port not open!")
            case "!silent":
                if len(uinput_argv) == 2:
                    silent_mode = not silent_mode
                else:
                    silent_mode = int(uinput_argv[2])
            case _:
                try:
                    handle_cmd(cmd, uinput_argv)
                except KeyboardInterrupt:
                    pass
                except Exception as e:
                    print(e)
                
def helper(in_interactive, caller):
    print("ernie commands:")
    print(caller + " raw [COMMAND]                               : send a raw command, only adds checksum           : -----")
    print(caller + " nop                                         : ping ernie                                       : 0x100")
    print(caller + " mode [USE_FAST?] [USE_BIN?]                 : [true/false] 115200 and binary uart modes        : 0x102")
    print(caller + " info                                        : get hardware & ernie info                        : 0x101")
    print(caller + " get-date-string                             : get ernie firmware date string                   : 0x107")
    print(caller + " power-off / power-on / power-fsm            : set new power state                              : 0x105")
    print(caller + " get-power                                   : get current power state                          : 0x106")
    print(caller + " get-kr600                                   : read some ID with maika command 4, off 0x120     : 0x120")
    print(caller + " maika-0 [OFFu16]                            : read some data with maika command 0              : 0x121")
    print(caller + " nvs-read [OFFu16] [SIZEu8]                  : read nvs                                         : 0x131")
    print(caller + " nvs-read-range [OFFu16] [ENDu16] [STEPu8]   : read and print nvs in STEP-sized blocks          : -----")
    print(caller + " nvs-write [OFFu16] [SIZEu8] [DATA]          : write nvs                                        : 0x132")
    print(caller + " confzz-ro / confzz-rw                       : block/allow confzz writes                        : 0x144 / 0x143")
    print(caller + " confzz-read [OFFu16] [SIZEu8]               : read confzz                                      : 0x141")
    print(caller + " confzz-read-range [OFFu16] [ENDu16] [STEPu8]: read and print confzz in STEP-sized blocks       : -----")
    print(caller + " confzz-write [OFFu16] [SIZEu8] [DATA]       : write backup confzz                              : 0x142")
    print(caller + " confzz-apply                                : write backup confzz to main confzz               : 0x145")
    print(caller + " invs-read [OFFu16] [SIZEu8]                 : read internal nvs                                : 0x154")
    print(caller + " invs-read-id [IDu8]                         : read internal nvs by id                          : 0x153")
    print(caller + " invs-read-range [OFFu16] [ENDu16] [STEPu8]  : read and print internal nvs in STEP-sized blocks : -----")
    print(caller + " wipe-nvs                                    : wipe NVS with 0xFF                               : 0x160")
    print(caller + " reset / reset-hard                          : soft-reset / hard reset ernie                    : 0x161 / 0x162")
    print(caller + " kill                                        : full, hard shutdown of all components            : 0x163")
    print(caller + " reset-bic                                   : reset the battery controller                     : 0x182")
    print(caller + " unlock-1 / lock-1                           : un/lock the T1 lock                              : 0x104 / 0x103")
    print(caller + " unlock-4 / lock-4                           : un/lock the T4 lock with a passcode              : 0x900 / 0x901")
    print(caller + " handshake-0 / handshake-1 / handshake-E     : authenticate with the selected keyset            : 0x110")
    print(caller + " unlock-qa                                   : unlock the T1 and T8 locks                       : 0x103 + 0x110 (E)")
    print(caller + " unlock-nvs                                  : unlock the T1 and T2 locks                       : 0x103 + 0x110 (1)")
    print(caller + " unlock-sdboot                               : unlock the T1 lock and boot into SD mode         : 0x103 + 0x110 (0)")
    print(caller + " unlock-all                                  : unlock 1,4,qa,nvs,sdboot                         : -----")
    print(caller + " [COMMANDu16] <SIZEu16> <DATA>               : execute a command, e.g. '0x105 0x2 03'           : -----")
    
    print("")
    if in_interactive:
        print("client commands:")
        print(caller + " !exit                                       : exit the client")
        print(caller + " !open [PORT] [BAUDRATE]                     : open & use PORT")
        print(caller + " !close                                      : close currently used port")
        print(caller + " !wait                                       : wait for ernie to send something")
        print(caller + " !silent                                     : toggle verbose level, argument '2' sets level to none")
    else:
        print("client commands:")
        print(caller + " !i                                          : enter an interactive session")

if __name__ == "__main__":
    uinput_argv = sys.argv

    if len(uinput_argv) == 1:
        helper(False, uinput_argv[0])
        exit(0)
       
    cmd = uinput_argv[1]

    if cmd[:1] == "!":
        interactive()
    else:
        try:
            handle_cmd(cmd, uinput_argv)
        except KeyboardInterrupt:
            pass
        except Exception as e:
            print(e)
    
    client.close()
    

#client.send_cmd(cmd)
#response = client.read_line()
#print(response.decode("ascii"), end ='')

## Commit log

2022-10-01 power states
2022-10-01 more power states
2023-03-10 Gerbers for a PCH-1000/PDEL-1000 JIG board
    Original repo available here: https://github.com/mathieulh/PCH-1000-JIG-PCB
2023-03-10 Removed a small leftover trace that wasn't connected to anything.
2023-03-14 Added the 3.3V PCH-1000 JIG Circuit with updated values.
2023-03-15 Uses 0805 Resistors and smaller footprint PCB
2023-03-16 Footprint reduced from 23.1 x 11.3mm(0.91 x 0.44 inches) to 19.3 x 11mm(0.76 x 0.43 inches); Should fit within the cradle.
    Footprint reduced from 23.1 x 11.3mm(0.91 x 0.44 inches) to 19.3 x 11mm(0.76 x 0.43 inches); Should fit within the cradle.
2023-03-16 Updated silkscreen
2023-03-16 fixed a trace
2023-03-16 smallest footprint yet, probably the last revision
2023-08-03 Added PCH-1000 PCB (final design)
    [PCH-1000JIG-B_Cu.gbr, PCH-1000JIG-B_Mask.gbr, PCH-1000JIG-B_Paste.gbr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]
2023-08-03 Update README.md
    board is tested and working
2023-08-03 Updated readme and BOM
2023-08-04 Kicad version of the UDC connector footprint.
2023-08-04 Added PCH-2XXX JIG board
    Initial board revision
    [PCH-2xxxJIG_0805_Nano-B_Cu.gbr, PCH-2xxxJIG_0805_Nano-B_Mask.gbr, PCH-2xxxJIG_0805_Nano-B_Paste.gbr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]
2023-08-04 New 1.4 THT revision
    New 1.4 THT revision with the option to solder an UC connector directly to the board
    [PCH-1xxxJIG_THT_1.4-B_Cu.gbr, PCH-1xxxJIG_THT_1.4-B_Mask.gbr, PCH-1xxxJIG_THT_1.4-B_Paste.gbr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]
2023-08-04 changed UDC silkscreen label
    [PCH-1xxxJIG_THT_1.4-B_Cu.gbr, PCH-1xxxJIG_THT_1.4-B_Mask.gbr, PCH-1xxxJIG_THT_1.4-B_Paste.gbr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]
2023-08-04 ALT Design deprecated
    [PCH-1000JIG-B_Cu.gbr, PCH-1000JIG-B_Mask.gbr, PCH-1000JIG-B_Paste.gbr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]
2023-08-04 New placement for the UDC connector.
    [PCH-1xxxJIG_THT_1.5-B_Cu.gbr, PCH-1xxxJIG_THT_1.5-B_Mask.gbr, PCH-1xxxJIG_THT_1.5-B_Paste.gbr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]
2023-08-05 Added a 5V version
    Added a 5V version (yet to be tested)
    this would allow to power the PS VITA from the UART module 5V lead while JIG is enabled.
    [PCH-2xxxJIG_0805_Nano-B_Cu.gbr, PCH-2xxxJIG_0805_Nano-B_Mask.gbr, PCH-2xxxJIG_0805_Nano-B_Paste.gbr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]
2023-08-07 Missing Bottom mask?
    [PCH-1xxxJIG_THT_1.4-B_Cu.gbr, PCH-1xxxJIG_THT_1.4-B_Mask.gbr, PCH-1xxxJIG_THT_1.4-B_Paste.gbr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]
2023-08-07 Wrong files uploaded
    [PCH-2xxxJIG_0805_Nano-B_Cu.gbr, PCH-2xxxJIG_0805_Nano-B_Mask.gbr, PCH-2xxxJIG_0805_Nano-B_Paste.gbr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]
2023-08-07 Missing bottom soldermask?
    [PCH-2xxxJIG_0805_Nano.kicad_pcb]
2023-08-09 Fixed a bad bridge
    [PCH-2xxxJIG_0805_Nano-B_Cu.gbr, PCH-2xxxJIG_0805_Nano-B_Mask.gbr, PCH-2xxxJIG_0805_Nano-B_Paste.gbr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]
2023-08-10 Added JIG mutliboard
    Added JIG mutliboard Currently handles PCH-1K/PDEL/PTEL and PCH-2K at both 3.3V and 5V
    * TODO: Add VTE support.
    [JIG_MULTI-B_Cu.gbr, JIG_MULTI-B_Mask.gbr, JIG_MULTI-B_Paste.gbr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]
2023-08-10 fixed silkscreen typo
    [JIG_MULTI-B_Cu.gbr, JIG_MULTI-B_Mask.gbr, JIG_MULTI-B_Paste.gbr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]
2023-08-10 Update README.md
    smaller footprint
2023-08-10 Update README.md
    better silkscreen placement
2023-08-22 Added version 2.0
    [JIG_MULTI-B_Cu.gbr, JIG_MULTI-B_Mask.gbr, JIG_MULTI-B_Paste.gbr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]
2023-08-22 Added alternative JIG design (closer to what the real JIG may have been like)
    Added alternative JIG design (closer to what the real JIG may have been like) requires a switch to switch between PCH1K and PCH2k
    [JIG SWITCH-B_Cu.gbr, JIG SWITCH-B_Mask.gbr, JIG SWITCH-B_Paste.gbr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]
2023-08-25 Fixed resistor value for 5V circuit
    [JIG_MULTI-B_Cu.gbr, JIG_MULTI-B_Mask.gbr, JIG_MULTI-B_Paste.gbr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]
2023-08-25 Added a warning label at the back of the board
    [JIG_MULTI-B_Cu.gbr, JIG_MULTI-B_Mask.gbr, JIG_MULTI-B_Paste.gbr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]
2023-08-25 Changed wrong resistor value
    [PCH-1000JIG_0805_Nano_5V-B_Cu.gbr, PCH-1000JIG_0805_Nano_5V-B_Mask.gbr, PCH-1000JIG_0805_Nano_5V-B_Paste.gbr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]
2023-08-25 Reversed back silkscreen text
    [PCH-1000JIG_0805_Nano_5V-B_Cu.gbr, PCH-1000JIG_0805_Nano_5V-B_Mask.gbr, PCH-1000JIG_0805_Nano_5V-B_Paste.gbr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]
2023-08-25 Used proper footprints for some of the pads that were missing them.
    [JIG_MULTI-B_Cu.gbr, JIG_MULTI-B_Mask.gbr, JIG_MULTI-B_Paste.gbr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]
